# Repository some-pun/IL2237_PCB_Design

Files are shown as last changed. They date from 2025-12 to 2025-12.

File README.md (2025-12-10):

# IL2237_PCB_Design
The purpose of this project is to create an 4 layer PCB functioning as an ESP32 DevKit which can be used for a variety of applications. 

# Key Features 
- ESP32-C3 microcontroller
- USB-to-UART Bridge
- LiPo charger and battery management circuit
- Flash and SD card memory module
- Optical, audio and environment sensors

# Tool used
- KiCAD 9

# Files
Project, Schematic, Layout and Gerber Files are uploaded in this repository

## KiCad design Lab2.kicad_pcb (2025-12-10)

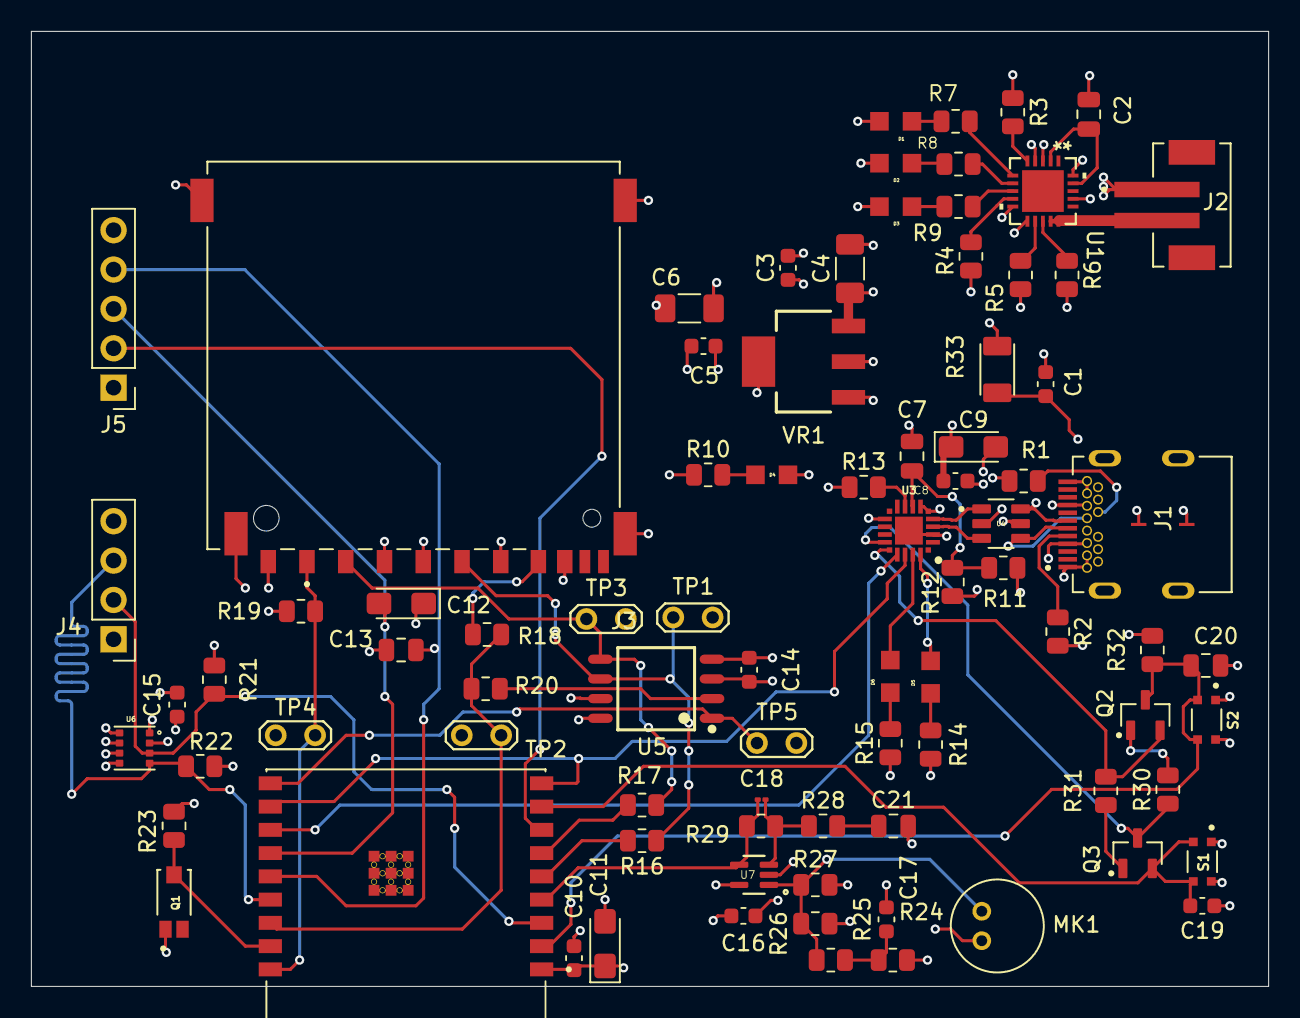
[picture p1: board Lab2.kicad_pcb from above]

Board: 4 copper layers, 79.8 x 61.6 mm, 84 parts (0 on the bottom side), 58 nets.

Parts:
C1, C3, C5, C8, C10, C14, C15, C16, C17, C19: 0.1u; C_0603_1608Metric
C2, C7, C20, C21: 1u; C_0805_2012Metric
C4, C6: 10u; C_1206_3216Metric_Pad1.33x1.80mm_HandSolder
C9: 4.7u; CP_EIA-3216-18_Kemet-A_HandSolder
C11: 10u; CP_EIA-3216-18_Kemet-A_HandSolder
C12: 0.1u; CP_EIA-3216-18_Kemet-A_HandSolder
C13: 10u; C_0805_2012Metric
C18: 0.1n; C_01005_0402Metric
D1, D4, D5: LTST-C170KRKT; DIOC200X125X110
D2: LTST-C170TBKT; DIOC200X125X110
D3, D6: LTST-C170KGKT; DIOC200X125X110
J1: SS-52400-003; BELFUSE_SS-52400-003
J2: B2B-PH-SM4-TB; JST_B2B-PH-SM4-TB
J3: GSD090012SEU; AMPHENOL_GSD090012SEU
J4: Conn_01x04_Pin; PinHeader_1x04_P2.54mm_Vertical
J5: Conn_01x05_Pin; PinHeader_1x05_P2.54mm_Vertical
MK1: CMC-5042PF-AC; CUI_CMC-5042PF-AC
Q1: TEMT6000X01; TRANS_TEMT6000X01
Q2, Q3: BC817; SOT95P230X110-3N
R1, R2: 5k1; R_0805_2012Metric
R3, R4, R23, R28, R30, R31, R32: 10k; R_0805_2012Metric
R5: 20k; R_0805_2012Metric
R6, R24, R25: 2k; R_0805_2012Metric
R7, R8, R9, R10, R14, R15: 470; R_0805_2012Metric
R11: 22k1; R_0805_2012Metric
R12: 47k5; R_0805_2012Metric
R13, R19: 1k; R_0805_2012Metric
R16, R17, R18, R20: 50; R_0805_2012Metric
R21, R22: 4k7; R_0805_2012Metric
R26, R27: 1M; R_0805_2012Metric
R29: 100k; R_0805_2012Metric
R33: 0ZCA0075FF2G; RESC3216X125N
S1, S2: USLPT2819DT2TR; SW_USLPT2819DT2TR
TP1, TP2, TP3, TP4, TP5: TestPoint; TestPoint_2Pads_Pitch2.54mm_Drill0.8mm
U1: MCP73871-4CCI/ML; QFN20_4x4MC_MCH
U2: ESP32-C3-WROOM-02-H4; MODULE_ESP32-C3-WROOM-02-H4
U3: CP2102N-A02-GQFN20; WFQFN-20
U4: USBLC6-2SC6; SOT95P280X145-6N
U5: W25Q32JVSSIQ; SOIC127P790X216-8N
U6: BME280; PSON65P250X250X100-8N
U7: MAX4466EXK; SOT65P210X110-5N
VR1: LM1117MPX-3.3; VREG_LM1117MPX-3.3

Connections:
+3.3V: C5.1, C6.1, C8.1, C9.1, C10.1, C11.1, C12.1, C13.1, C14.1, C15.1, C16.1, J3.4 (VDD1), J4.1, J5.1, R10.1, R13.1, R14.1, R15.1, R19.1, R21.1, R22.1, R23.1, R24.1, R26.1, R32.1, U2.1 (3V3), U3.6 (VDD), U3.7 (VREGIN), U5.3 (~WP(IO2)), U5.7 (~HOLD/~RESET(IO3)), U5.8 (VCC), U6.2 (CSB), U6.6 (VDDIO), U6.8 (VDD), U7.5 (VCC), VR1.2 (VOUT_2), VR1.4 (VOUT_4)
+5V: C3.1, C4.1, U1.20 (OUT), VR1.3 (VIN)
/+5V_USB: D1.+, D2.+, D3.+, R33.2, U1.4 (PROG2), U1.17 (CE)
/ESP32-C3-02/BOOT: C19.1, Q3.2, S1.3, S1.4, U2.8 (IO9)
/ESP32-C3-02/CS: TP5.1, U2.10 (IO10), U5.1 (~CS)
/ESP32-C3-02/CS_SD: J3.1 (CD/DAT3), R19.2, TP4.1, U2.18 (IO0)
/ESP32-C3-02/DTR: Q3.3, R30.1, U3.15 (CTS)
/ESP32-C3-02/EN: C20.1, Q2.3, R32.2, S2.3, S2.4, U2.2 (EN)
/ESP32-C3-02/GPI08: J5.2, U2.7 (IO8)
/ESP32-C3-02/GPI018: J5.3, U2.13 (IO18)
/ESP32-C3-02/GPI019: J5.4, U2.14 (IO19)
/ESP32-C3-02/MIC_OUT: C18.2, R29.2, U2.4 (IO5), U7.4 (OUT)
/ESP32-C3-02/MISO_DO: R18.1, R20.2, TP2.1, U2.16 (IO2)
/ESP32-C3-02/MOSI_DI: J3.2 (CMD), R17.1, TP3.1, U5.5 (DI(IO0))
/ESP32-C3-02/PHOTO_C: Q1.3, R23.2, U2.17 (IO1)
/ESP32-C3-02/RTS: Q2.2, R31.1, U3.16 (RTS)
/ESP32-C3-02/RX_TX: U2.12 (TXD), U3.17 (RXD)
/ESP32-C3-02/SCL: J4.3, R22.2, U2.15 (IO3), U6.4 (SCK)
/ESP32-C3-02/SCL_K: J3.5 (CLK), R16.1, TP1.1, U5.6 (CLK)
/ESP32-C3-02/SDA: J4.2, R21.2, U2.3 (IO4), U6.3 (SDI)
/ESP32-C3-02/TX_RX: U2.11 (RXD), U3.18 (TXD)
/ESP32-C3-02/USB_D+: U3.4 (D+), U4.3
/ESP32-C3-02/USB_D-: U3.5 (D-), U4.1
/PWR_LED: D4.-, R10.2
/USB_DN: J1.A7 (DN1), J1.B7 (DN2), U4.6
/USB_DP: J1.A6 (DP1), J1.B6 (DP2), U4.4
/VBAT: J2.2, U1.14 (VBAT), U1.15 (VBAT)
/VBUS: C1.1, J1.A4 (VBUSA1), J1.A9 (VBUSA2), J1.B4 (VBUSB1), J1.B9 (VBUSB2), R11.1, R33.1, U4.5
GND: C1.2, C2.2, C3.2, C4.2, C5.2, C6.2, C7.2, C8.2, C9.2, C10.2, C11.2, C12.2, C13.2, C14.2, C15.2, C16.2, C17.1, C19.2, C20.2, C21.2, D4.+, J1.A1 (GNDA1), J1.A12 (GNDA2), J1.B1 (GNDB1), J1.B12 (GNDB2), J1.G1 (GND/SHIELD), J1.G2 (GND/SHIELD), J1.G3 (GND/SHIELD), J1.G4 (GND/SHIELD), J1.S1 (GND/SHIELD), J1.S2 (GND/SHIELD), J1.S3 (GND/SHIELD), J1.S4 (GND/SHIELD), J2.1, J3.3 (VSS1), J3.6 (VSS2), J3.8 (DAT1), J3.9 (DAT2), J3.G1 (SHIELD_GND), J3.G2 (SHIELD_GND), J3.G3 (SHIELD_GND), J3.G4 (SHIELD_GND), J4.4, J5.5, MK1.GND, Q1.1, R1.2, R2.2, R3.2, R4.1, R5.1, R6.2, R12.2, R27.2, S1.1, S1.2, S2.1, S2.2, U1.3 (SEL), U1.10 (VSS), U1.11 (VSS), U2.9 (GND), U2.19 (GND), U2.20 (GND), U2.21 (GND), U2.22 (GND), U2.23 (GND), U2.24 (GND), U2.25 (GND), U2.26 (GND), U2.27 (GND), U2.28 (GND), U2.29 (GND), U2.30 (GND), U2.31 (GND), U2.32 (GND), U2.33 (GND), U2.34 (GND), U2.35 (GND), U2.36 (GND), U2.37 (GND), U2.38 (GND), U2.39 (GND), U3.3 (GND), U3.12 (GND), U3.EXP (GND), U4.2, U5.4 (GND), U6.1 (GND), U6.5 (SDO), U6.7 (GND), U7.2 (GND), VR1.1 (GND)
unnamed: C17.2, R24.2, R25.1
unnamed: C21.1, R28.2
unnamed: D1.-, R7.2
unnamed: D2.-, R8.2
unnamed: D3.-, R9.2
unnamed: D5.-, R14.2
unnamed: D6.-, R15.2
unnamed: J1.A5 (CC1), R2.1
unnamed: J1.B5 (CC2), R1.1
unnamed: J3.7 (DAT0), R18.2
unnamed: Q2.1, R30.2
unnamed: Q3.1, R31.2
unnamed: R7.1, U1.6 (*PG)
unnamed: R4.2, U1.9 (*TE)
unnamed: R6.1, U1.13 (PROG1)
unnamed: R5.2, U1.12 (PROG3)
unnamed: R9.1, U1.8 (STAT1/*LBO)
unnamed: R8.1, U1.7 (STAT2)
unnamed: R3.1, U1.5 (THERM)
unnamed: C2.1, U1.2 (VPCC), U1.19 (IN)
unnamed: R16.2, U2.5 (IO6)
unnamed: R17.2, U2.6 (IO7)
unnamed: D5.+, U3.20 (GPIO2/TXT)
unnamed: D6.+, U3.19 (GPIO3/RXT)
unnamed: R13.2, U3.9 (RSTB)
unnamed: C7.1, R11.2, R12.1, U3.8 (VBUS)
unnamed: R20.1, U5.2 (DO(IO1))
unnamed: MK1.OUT, R25.2, R26.2, R27.1, U7.1 (IN+)
unnamed: C18.1, R28.1, R29.1, U7.3 (IN-)
